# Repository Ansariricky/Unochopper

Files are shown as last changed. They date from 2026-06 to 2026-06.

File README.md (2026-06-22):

<<<<<<< HEAD
# Hardware

This repository contains hardware design files for various products and subsystems, including but not limited to:

- Flight Controllers (FC)
- Electronic Speed Controllers (ESC)
- Radio Control Systems (RC)
- Video Transmitters (VTX)
- Power Distribution Units (PDU)
- Sensor Boards
- Companion Computers
- Other supporting avionics and embedded hardware

## Naming Convention

Project directories shall follow the format:

    <MCU_OR_CPU>_<HARDWARE>_RevX

Examples:

    STM32F405_FlightController_Rev1
    STM32F405_ESC_Rev1
    ESP32S3_RC_Rev1
    ESP32S3_VTX_Rev1
    RPiCM4_CompanionComputer_Rev1

### Rules

- Use underscores (_) as separators.
- Do not use spaces in directory names.
- MCU/CPU name must appear first.
- Hardware name must appear second.
- Revision number must appear last.

## Repository Contents

Each project directory may contain:

- Schematics
- PCB Layouts
- Manufacturing Files
- Bill of Materials (BOM)
- Assembly Documentation
- Design Notes

## Revision Policy

New hardware revisions shall be created as separate directories following the established naming convention. Previous revisions should be retained for traceability and historical reference.

=======
# Hardware

This repository contains hardware design files for various products and subsystems, including but not limited to:

- Flight Controllers (FC)
- Electronic Speed Controllers (ESC)
- Radio Control Systems (RC)
- Video Transmitters (VTX)
- Power Distribution Units (PDU)
- Sensor Boards
- Companion Computers
- Other supporting avionics and embedded hardware

## Naming Convention

Project directories shall follow the format:

    <MCU_OR_CPU>_<HARDWARE>_RevX

Examples:

    STM32F405_FlightController_Rev1
    STM32F405_ESC_Rev1
    ESP32S3_RC_Rev1
    ESP32S3_VTX_Rev1
    RPiCM4_CompanionComputer_Rev1

### Rules

- Use underscores (_) as separators.
- Do not use spaces in directory names.
- MCU/CPU name must appear first.
- Hardware name must appear second.
- Revision number must appear last.

## Repository Contents

Each project directory may contain:

- Schematics
- PCB Layouts
- Manufacturing Files
- Bill of Materials (BOM)
- Assembly Documentation
- Design Notes

## Revision Policy

New hardware revisions shall be created as separate directories following the established naming convention. Previous revisions should be retained for traceability and historical reference.

>>>>>>> 076c8ab1df7aa20a5a2c2d71f1c9e05963331e4d

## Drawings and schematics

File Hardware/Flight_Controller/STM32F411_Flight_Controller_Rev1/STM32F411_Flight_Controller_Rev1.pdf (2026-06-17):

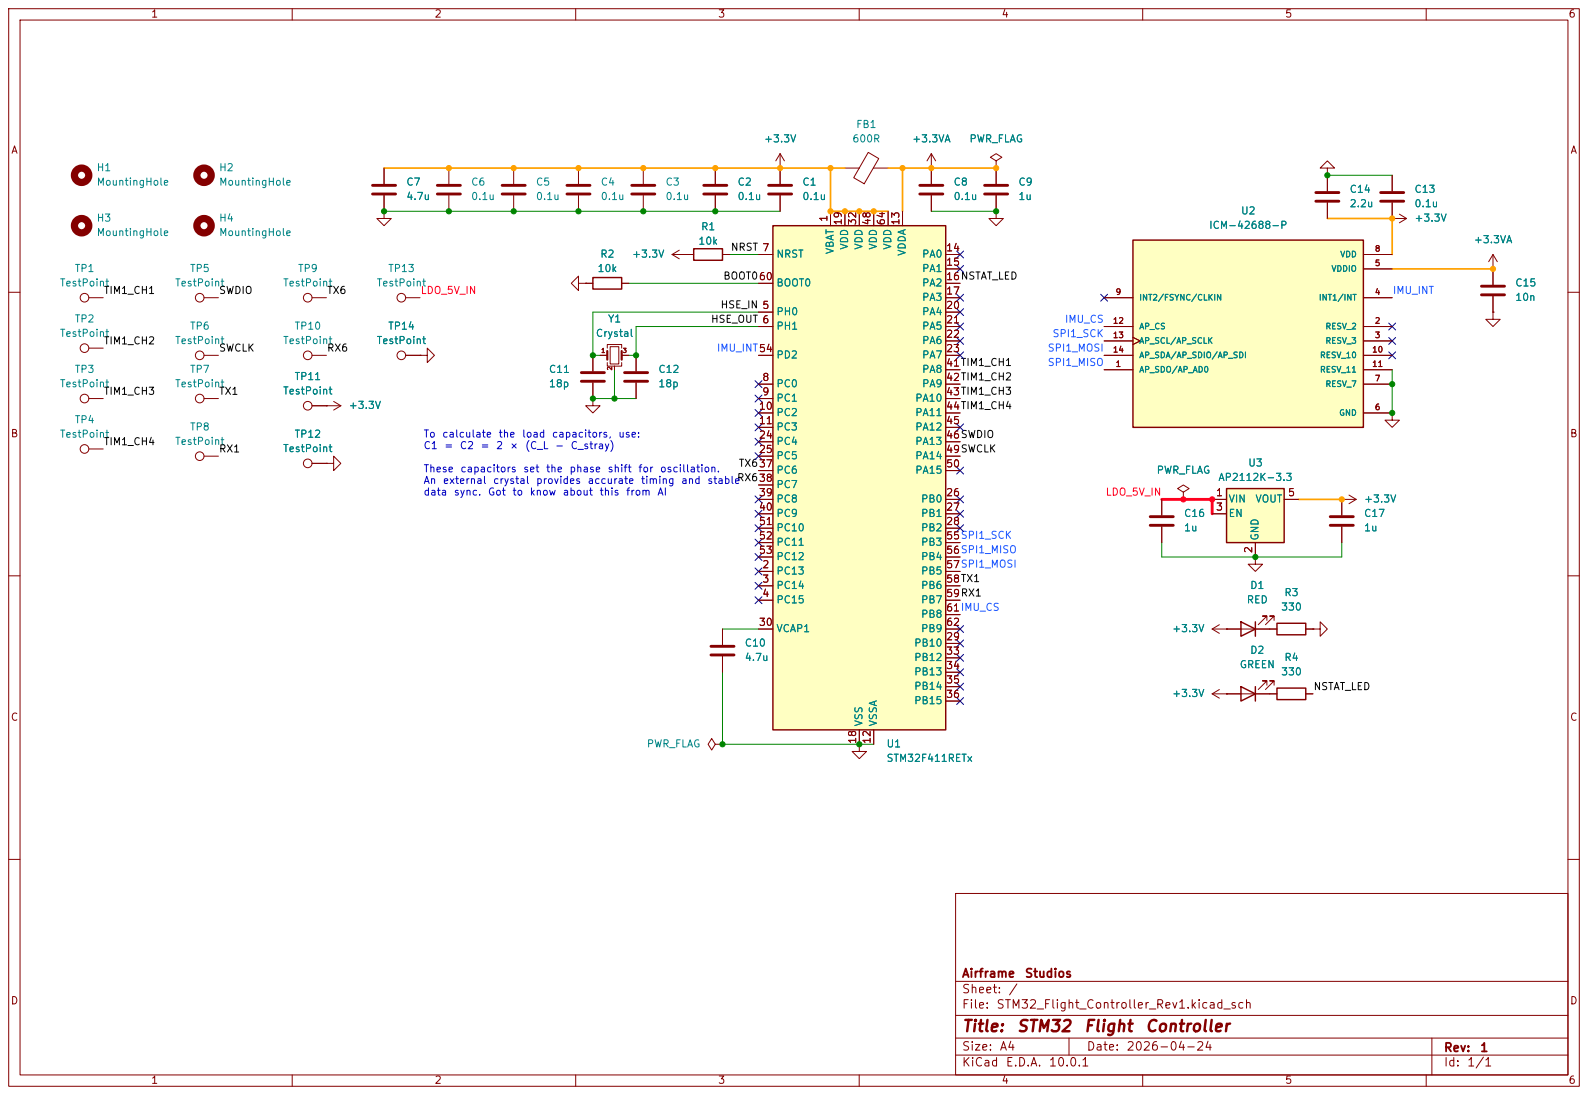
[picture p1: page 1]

Size: A4 | Rev: 1
KiCad E.D.A. 10.0.1 | Id: 1/1

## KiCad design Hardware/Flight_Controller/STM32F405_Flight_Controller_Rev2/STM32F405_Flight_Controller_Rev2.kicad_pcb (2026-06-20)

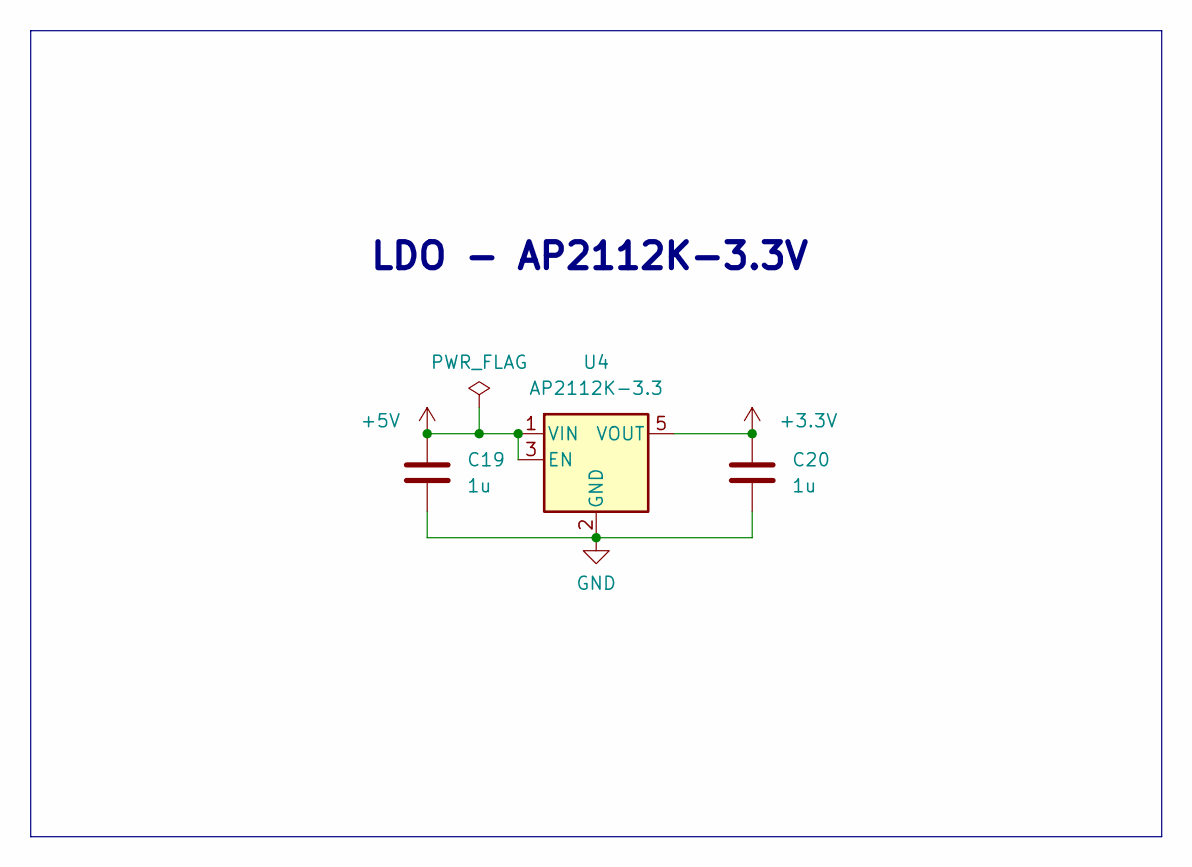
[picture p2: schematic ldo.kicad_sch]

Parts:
C19, C20: 1u; C_0603_1608Metric_Pad1.08x0.95mm_HandSolder
U4: AP2112K-3.3; SOT-23-5

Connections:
+3.3V: C20.1, U4.5 (VOUT); also elsewhere on the board
+5V: C19.1, U4.1 (VIN), U4.3 (EN); also elsewhere on the board
GND: C19.2, C20.2, U4.2 (GND); also elsewhere on the board

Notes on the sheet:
LDO - AP2112K-3.3V

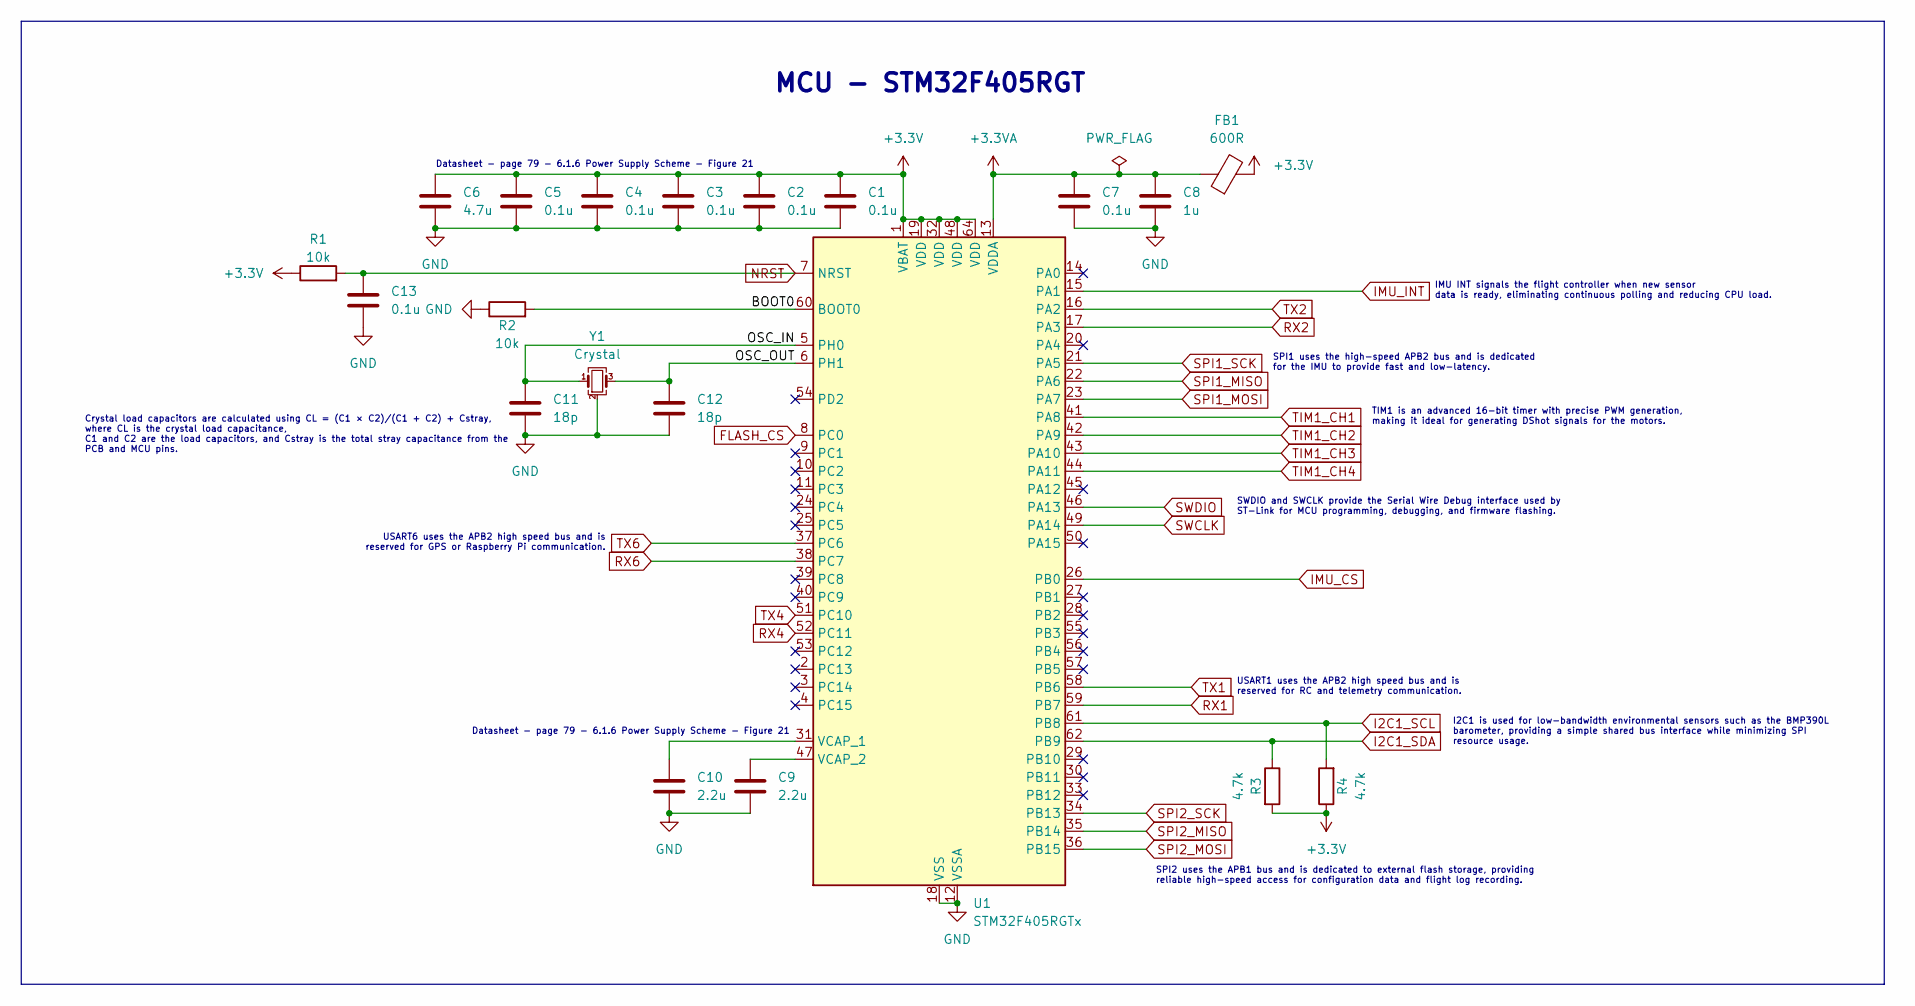
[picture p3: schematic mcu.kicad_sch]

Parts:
C1, C2, C3, C4, C5, C7, C13: 0.1u; C_0603_1608Metric_Pad1.08x0.95mm_HandSolder
C6: 4.7u; C_0603_1608Metric_Pad1.08x0.95mm_HandSolder
C8: 1u; C_0603_1608Metric_Pad1.08x0.95mm_HandSolder
C9, C10: 2.2u; C_0603_1608Metric_Pad1.08x0.95mm_HandSolder
C11, C12: 18p; C_0603_1608Metric_Pad1.08x0.95mm_HandSolder
FB1: 600R; L_0603_1608Metric_Pad1.05x0.95mm_HandSolder
R1, R2: 10k; R_0603_1608Metric_Pad0.98x0.95mm_HandSolder
R3, R4: 4.7k; R_0603_1608Metric_Pad0.98x0.95mm_HandSolder
U1: STM32F405RGTx; LQFP-64_10x10mm_P0.5mm
Y1: Crystal; Crystal_SMD_3225-4Pin_3.2x2.5mm_HandSoldering

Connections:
+3.3V: C1.1, C2.1, C3.1, C4.1, C5.1, C6.1, FB1.2, R1.1, R3.2, R4.1, U1.1 (VBAT), U1.19 (VDD), U1.32 (VDD), U1.48 (VDD), U1.64 (VDD); also elsewhere on the board
+3.3VA: C7.1, C8.1, FB1.1, U1.13 (VDDA)
/MCU/BOOT0: R2.2, U1.60 (BOOT0)
/MCU/OSC_IN: C11.1, U1.5 (PH0), Y1.1
/MCU/OSC_OUT: C12.1, U1.6 (PH1), Y1.3
FLASH_CS: U1.8 (PC0); also elsewhere on the board
GND: C1.2, C2.2, C3.2, C4.2, C5.2, C6.2, C7.2, C8.2, C9.2, C10.2, C11.2, C12.2, C13.2, R2.1, U1.12 (VSSA), U1.18 (VSS), U1.63 (VSS), Y1.2 (G), Y1.4 (G); also elsewhere on the board
I2C1_SCL: R4.2, U1.61 (PB8); also elsewhere on the board
I2C1_SDA: R3.1, U1.62 (PB9); also elsewhere on the board
IMU_CS: U1.26 (PB0); also elsewhere on the board
IMU_INT: U1.15 (PA1); also elsewhere on the board
NRST: C13.1, R1.2, U1.7 (NRST)
unnamed: C10.1, U1.31 (VCAP_1)
unnamed: C9.1, U1.47 (VCAP_2)
RX1: U1.59 (PB7); also elsewhere on the board
RX2: U1.17 (PA3); also elsewhere on the board
RX4: U1.52 (PC11); also elsewhere on the board
RX6: U1.38 (PC7); also elsewhere on the board
SPI1_MISO: U1.22 (PA6); also elsewhere on the board
SPI1_MOSI: U1.23 (PA7); also elsewhere on the board
SPI1_SCK: U1.21 (PA5); also elsewhere on the board
SPI2_MISO: U1.35 (PB14); also elsewhere on the board
SPI2_MOSI: U1.36 (PB15); also elsewhere on the board
SPI2_SCK: U1.34 (PB13); also elsewhere on the board
SWCLK: U1.49 (PA14); also elsewhere on the board
SWDIO: U1.46 (PA13); also elsewhere on the board
TIM1_CH1: U1.41 (PA8); also elsewhere on the board
TIM1_CH2: U1.42 (PA9); also elsewhere on the board
TIM1_CH3: U1.43 (PA10); also elsewhere on the board
TIM1_CH4: U1.44 (PA11); also elsewhere on the board
TX1: U1.58 (PB6); also elsewhere on the board
TX2: U1.16 (PA2); also elsewhere on the board
TX4: U1.51 (PC10); also elsewhere on the board
TX6: U1.37 (PC6); also elsewhere on the board

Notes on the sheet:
MCU - STM32F405RGT
IMU INT signals the flight controller when new sensor data is ready, eliminating continuous polling and reducing CPU load.
SPI2 uses the APB1 bus and is dedicated to external flash storage, providing reliable high-speed access for configuration data and flight log recording.
Crystal load capacitors are calculated using CL = (C1 × C2)/(C1 + C2) + Cstray, where CL is the crystal load capacitance, C1 and C2 are the load capacitors, and Cstray is the total stray capacitance from the PCB and MCU pins.
USART1 uses the APB2 high speed bus and is reserved for RC and telemetry communication.
SWDIO and SWCLK provide the Serial Wire Debug interface used by ST-Link for MCU programming, debugging, and firmware flashing.
I2C1 is used for low-bandwidth environmental sensors such as the BMP390L barometer, providing a simple shared bus interface while minimizing SPI resource usage.
TIM1 is an advanced 16-bit timer with precise PWM generation, making it ideal for generating DShot signals for the motors.
SPI1 uses the high-speed APB2 bus and is dedicated for the IMU to provide fast and low-latency.
USART6 uses the APB2 high speed bus and is reserved for GPS or Raspberry Pi communication.
Datasheet - page 79 - 6.1.6 Power Supply Scheme - Figure 21

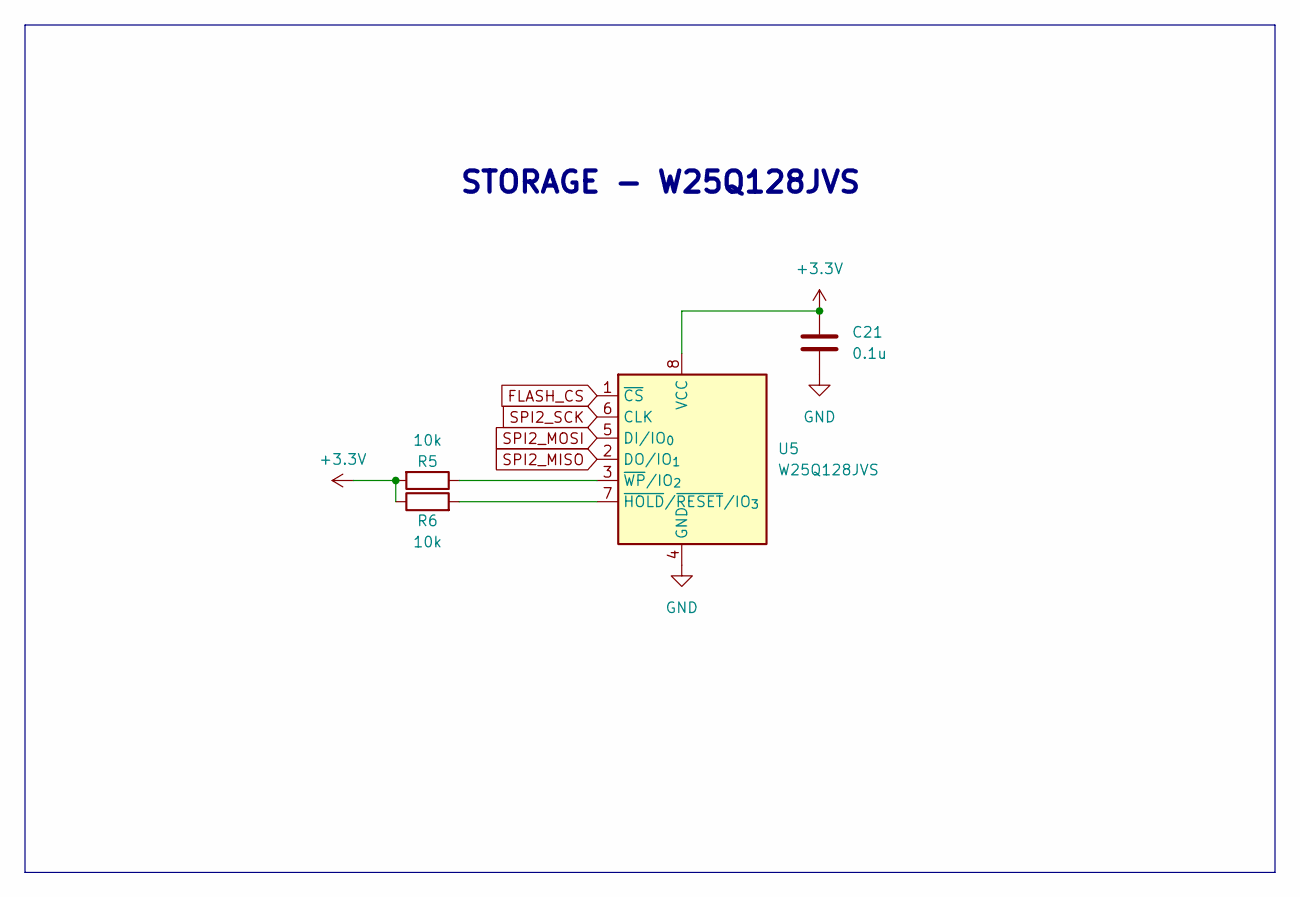
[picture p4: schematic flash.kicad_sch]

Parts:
C21: 0.1u; C_0603_1608Metric_Pad1.08x0.95mm_HandSolder
R5, R6: 10k; R_0603_1608Metric_Pad0.98x0.95mm_HandSolder
U5: W25Q128JVS; SOIC-8_5.3x5.3mm_P1.27mm

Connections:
+3.3V: C21.1, R5.2, R6.1, U5.8 (VCC); also elsewhere on the board
FLASH_CS: U5.1 (~CS); also elsewhere on the board
GND: C21.2, U5.4 (GND); also elsewhere on the board
unnamed: R6.2, U5.7 (~HOLD/~RESET/IO_{3})
unnamed: R5.1, U5.3 (~WP/IO_{2})
SPI2_MISO: U5.2 (DO/IO_{1}); also elsewhere on the board
SPI2_MOSI: U5.5 (DI/IO_{0}); also elsewhere on the board
SPI2_SCK: U5.6 (CLK); also elsewhere on the board

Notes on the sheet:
STORAGE - W25Q128JVS

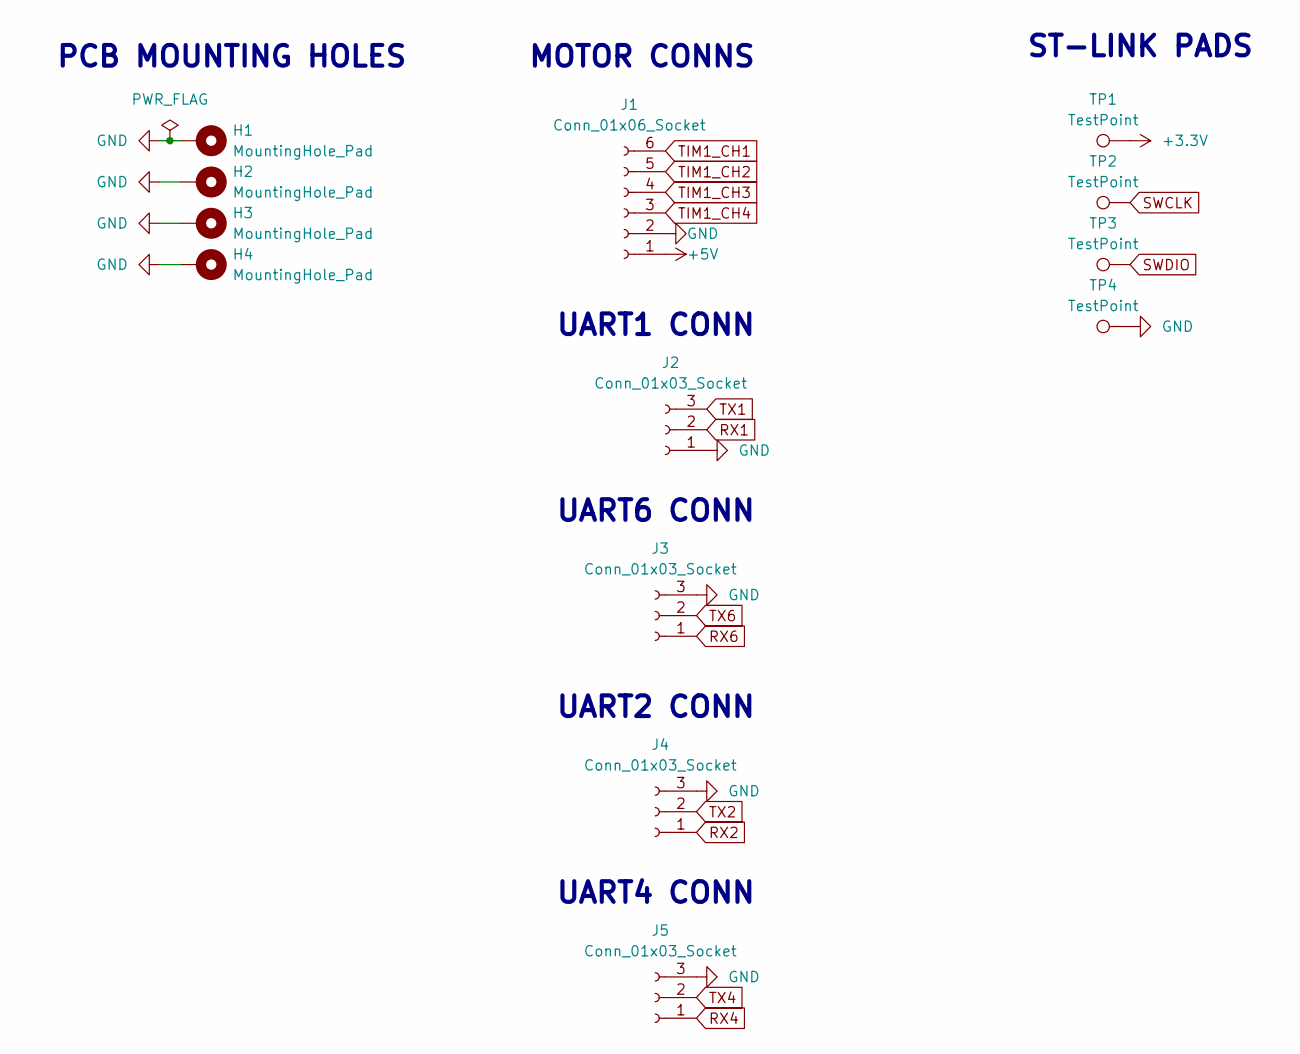
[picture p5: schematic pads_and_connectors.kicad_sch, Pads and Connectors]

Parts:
H1, H2, H3, H4: MountingHole_Pad; MountingHole_3.2mm_M3_Pad
J1: Conn_01x06_Socket; JST_SH_SM06B-SRSS-TB_1x06-1MP_P1.00mm_Horizontal
J2, J3, J4, J5: Conn_01x03_Socket; JST_SH_SM03B-SRSS-TB_1x03-1MP_P1.00mm_Horizontal
TP1, TP2, TP3, TP4: TestPoint; TestPoint_Pad_D1.5mm

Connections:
+3.3V: TP1.1 (1_1); also elsewhere on the board
+5V: J1.1; also elsewhere on the board
GND: H1.1 (1_1), H2.1 (1_1), H3.1 (1_1), H4.1 (1_1), J1.2, J2.1, J3.3, J4.3, J5.3, TP4.1 (1_1); also elsewhere on the board
RX1: J2.2; also elsewhere on the board
RX2: J4.1; also elsewhere on the board
RX4: J5.1; also elsewhere on the board
RX6: J3.1; also elsewhere on the board
SWCLK: TP2.1 (1_1); also elsewhere on the board
SWDIO: TP3.1 (1_1); also elsewhere on the board
TIM1_CH1: J1.6; also elsewhere on the board
TIM1_CH2: J1.5; also elsewhere on the board
TIM1_CH3: J1.4; also elsewhere on the board
TIM1_CH4: J1.3; also elsewhere on the board
TX1: J2.3; also elsewhere on the board
TX2: J4.2; also elsewhere on the board
TX4: J5.2; also elsewhere on the board
TX6: J3.2; also elsewhere on the board

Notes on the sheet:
UART2 CONN
UART4 CONN
UART1 CONN
MOTOR CONNS
UART6 CONN
PCB MOUNTING HOLES
ST-LINK PADS

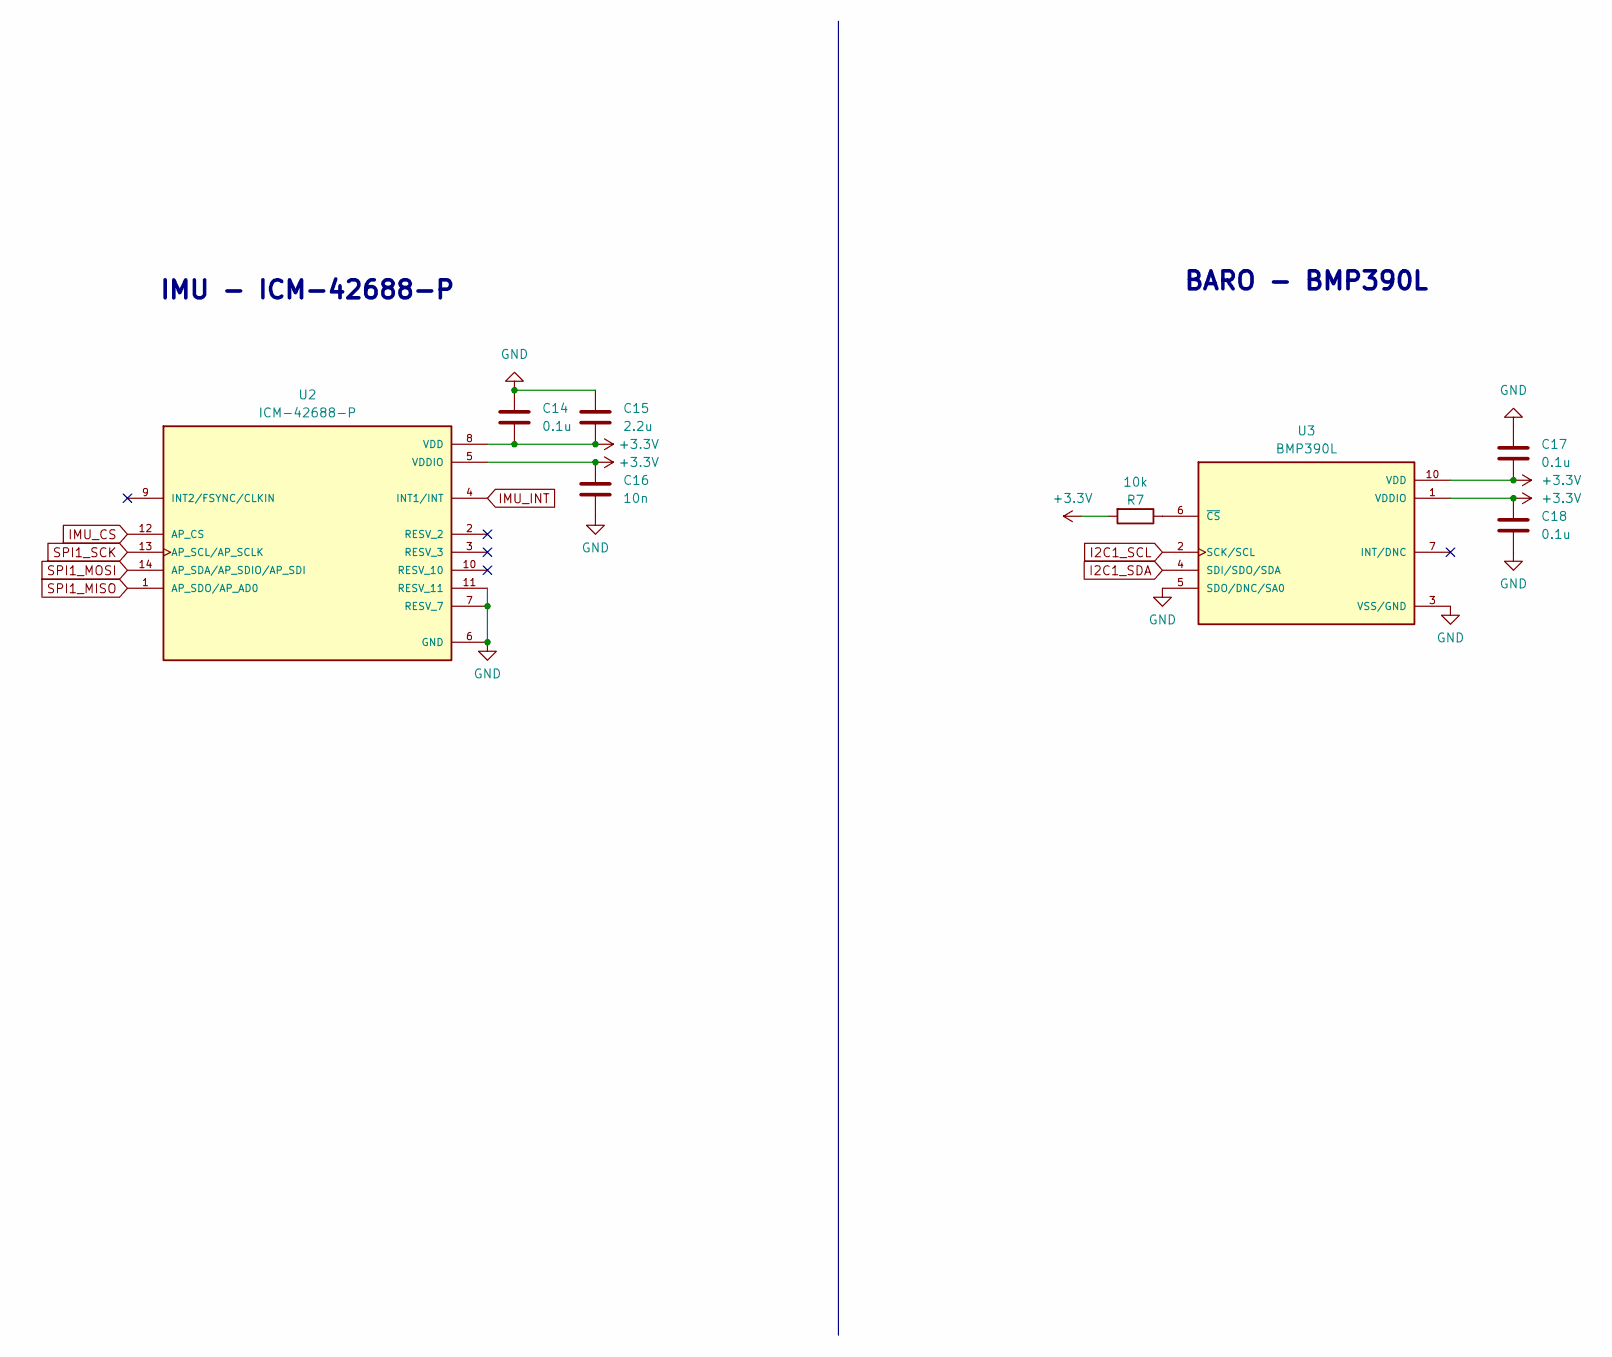
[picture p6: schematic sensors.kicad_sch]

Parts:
C14, C17, C18: 0.1u; C_0603_1608Metric_Pad1.08x0.95mm_HandSolder
C15: 2.2u; C_0603_1608Metric_Pad1.08x0.95mm_HandSolder
C16: 10n; C_0603_1608Metric_Pad1.08x0.95mm_HandSolder
R7: 10k; R_0603_1608Metric_Pad0.98x0.95mm_HandSolder
U2: ICM-42688-P; PARTREV 1.2
U3: BMP390L; PARTREV 1.7

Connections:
+3.3V: C14.2, C15.2, C16.1, C17.1, C18.1, R7.2, U2.5 (VDDIO), U2.8 (VDD), U3.1 (VDDIO), U3.10 (VDD); also elsewhere on the board
GND: C14.1, C15.1, C16.2, C17.2, C18.2, U2.6 (GND), U2.7 (RESV_7), U2.11 (RESV_11), U3.3 (VSS/GND), U3.5 (SDO/DNC/SA0), U3.8 (VSS/GND), U3.9 (VSS/GND); also elsewhere on the board
I2C1_SCL: U3.2 (SCK/SCL); also elsewhere on the board
I2C1_SDA: U3.4 (SDI/SDO/SDA); also elsewhere on the board
IMU_CS: U2.12 (AP_CS); also elsewhere on the board
IMU_INT: U2.4 (INT1/INT); also elsewhere on the board
unnamed: R7.1, U3.6 (~CS)
SPI1_MISO: U2.1 (AP_SDO/AP_AD0); also elsewhere on the board
SPI1_MOSI: U2.14 (AP_SDA/AP_SDIO/AP_SDI); also elsewhere on the board
SPI1_SCK: U2.13 (AP_SCL/AP_SCLK); also elsewhere on the board

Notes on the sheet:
IMU - ICM-42688-P
BARO - BMP390L

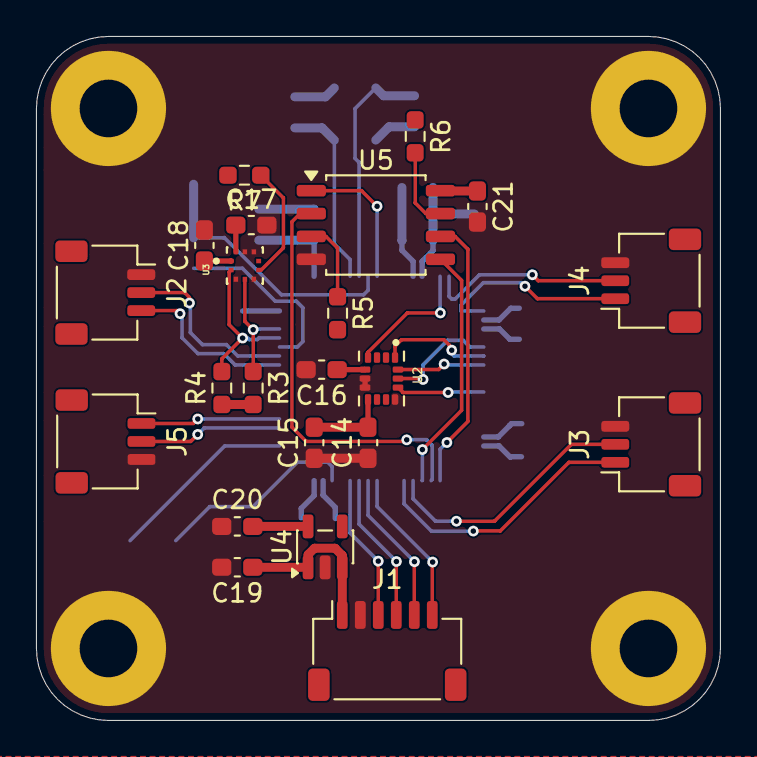
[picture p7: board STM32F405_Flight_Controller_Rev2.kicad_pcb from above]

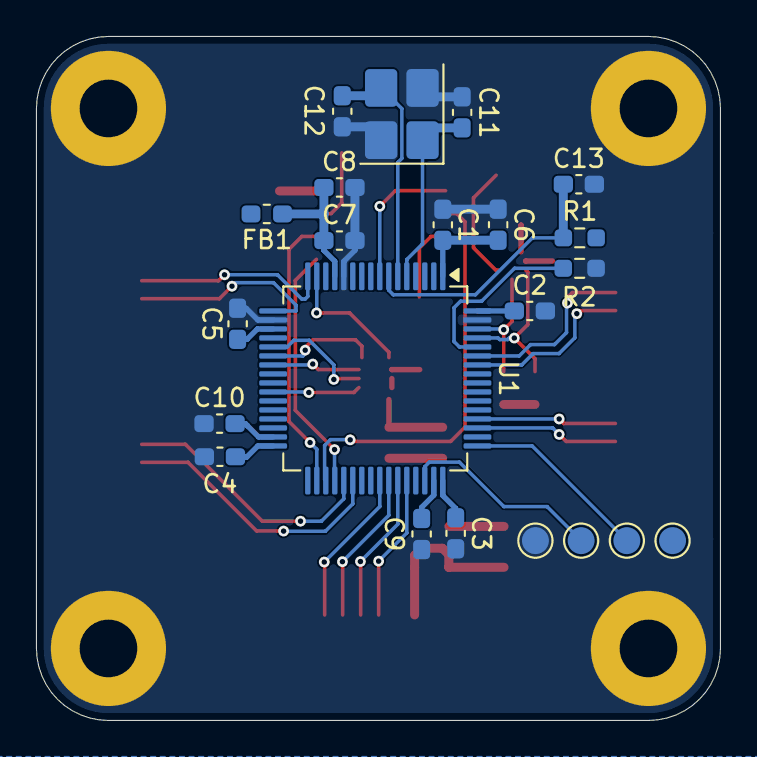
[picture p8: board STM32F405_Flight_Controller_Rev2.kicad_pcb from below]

Board: 4 copper layers, 38.0 x 38.0 mm, 48 parts (22 on the bottom side), 38 nets.

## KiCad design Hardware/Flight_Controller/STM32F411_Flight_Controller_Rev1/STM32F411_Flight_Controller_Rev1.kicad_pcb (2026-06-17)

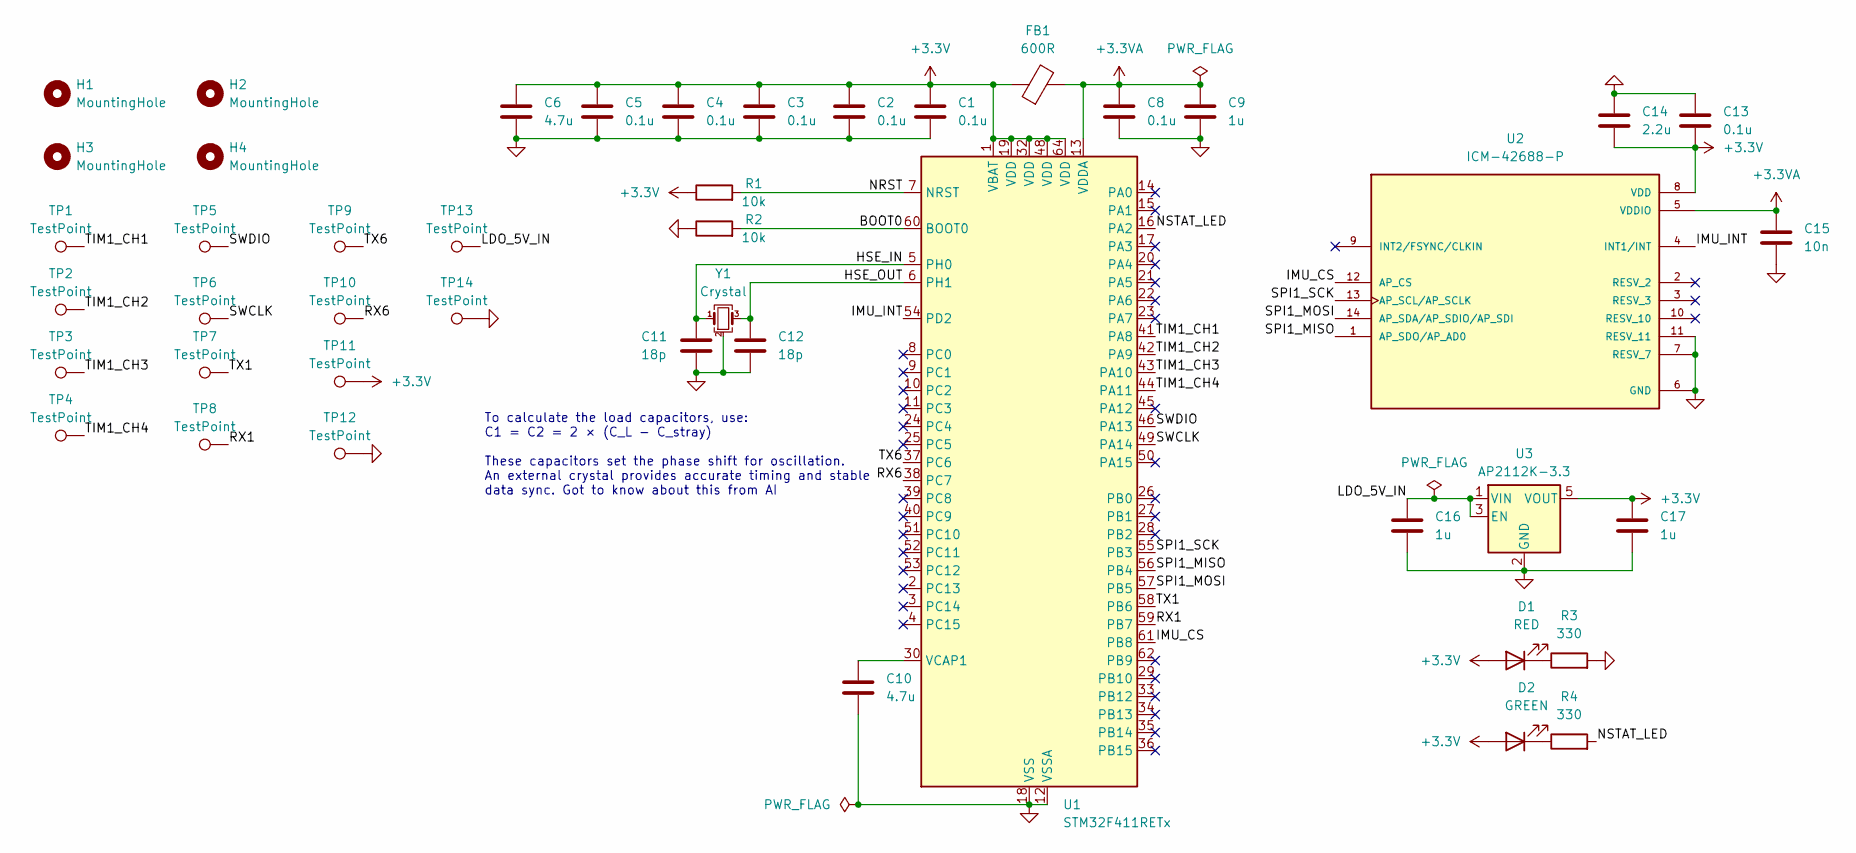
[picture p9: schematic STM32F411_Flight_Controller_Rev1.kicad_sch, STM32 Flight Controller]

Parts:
C1, C2, C3, C4, C5, C8, C13: 0.1u; C_0603_1608Metric_Pad1.08x0.95mm_HandSolder
C6, C10: 4.7u; C_0603_1608Metric_Pad1.08x0.95mm_HandSolder
C9, C16, C17: 1u; C_0603_1608Metric_Pad1.08x0.95mm_HandSolder
C11, C12: 18p; C_0603_1608Metric_Pad1.08x0.95mm_HandSolder
C14: 2.2u; C_0603_1608Metric_Pad1.08x0.95mm_HandSolder
C15: 10n; C_0603_1608Metric_Pad1.08x0.95mm_HandSolder
D1: RED; LED_0603_1608Metric_Pad1.05x0.95mm_HandSolder
D2: GREEN; LED_0603_1608Metric_Pad1.05x0.95mm_HandSolder
FB1: 600R; L_0603_1608Metric_Pad1.05x0.95mm_HandSolder
H1, H2, H3, H4: MountingHole; MountingHole_3.2mm_M3
R1, R2: 10k; R_0603_1608Metric_Pad0.98x0.95mm_HandSolder
R3, R4: 330; R_0603_1608Metric_Pad0.98x0.95mm_HandSolder
TP1, TP2, TP3, TP4, TP5, TP6, TP7, TP8, TP9, TP10, TP11, TP12, TP13, TP14: TestPoint; TestPoint_THTPad_1.0x1.0mm_Drill0.5mm
U1: STM32F411RETx; LQFP-64_10x10mm_P0.5mm
U2: ICM-42688-P; PARTREV 1.2
U3: AP2112K-3.3; SOT-23-5
Y1: Crystal; Crystal_SMD_3225-4Pin_3.2x2.5mm_HandSoldering

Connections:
+3.3V: C1.1, C2.1, C3.1, C4.1, C5.1, C6.1, C13.1, C14.1, C17.2, D1.2 (A), D2.2 (A), FB1.1, R1.1, TP11.1 (1_1), U1.1 (VBAT), U1.19 (VDD), U1.32 (VDD), U1.48 (VDD), U1.64 (VDD), U2.8 (VDD), U3.5 (VOUT); also elsewhere on the board
+3.3VA: C8.1, C9.1, C15.2, FB1.2, U1.13 (VDDA), U2.5 (VDDIO)
/BOOT0: R2.2, U1.60 (BOOT0)
/HSE_IN: C11.1, U1.5 (PH0), Y1.1
/HSE_OUT: C12.1, U1.6 (PH1), Y1.3
/IMU_CS: U1.61 (PB8), U2.12 (AP_CS)
/IMU_INT: U1.54 (PD2), U2.4 (INT1/INT)
/LDO_5V_IN: C16.2, TP13.1 (1_1), U3.1 (VIN), U3.3 (EN)
/NRST: R1.2, U1.7 (NRST)
/NSTAT_LED: R4.2, U1.16 (PA2)
/RX1: TP8.1 (1_1), U1.59 (PB7)
/RX6: TP10.1 (1_1), U1.38 (PC7)
/SPI1_MISO: U1.56 (PB4), U2.1 (AP_SDO/AP_AD0)
/SPI1_MOSI: U1.57 (PB5), U2.14 (AP_SDA/AP_SDIO/AP_SDI)
/SPI1_SCK: U1.55 (PB3), U2.13 (AP_SCL/AP_SCLK)
/SWCLK: TP6.1 (1_1), U1.49 (PA14)
/SWDIO: TP5.1 (1_1), U1.46 (PA13)
/TIM1_CH1: TP1.1 (1_1), U1.41 (PA8)
/TIM1_CH2: TP2.1 (1_1), U1.42 (PA9)
/TIM1_CH3: TP3.1 (1_1), U1.43 (PA10)
/TIM1_CH4: TP4.1 (1_1), U1.44 (PA11)
/TX1: TP7.1 (1_1), U1.58 (PB6)
/TX6: TP9.1 (1_1), U1.37 (PC6)
GND: C1.2, C2.2, C3.2, C4.2, C5.2, C6.2, C8.2, C9.2, C10.2, C11.2, C12.2, C13.2, C14.2, C15.1, C16.1, C17.1, R2.1, R3.2, TP12.1 (1_1), TP14.1 (1_1), U1.12 (VSSA), U1.18 (VSS), U1.31 (VSS), U1.47 (VSS), U1.63 (VSS), U2.6 (GND), U2.7 (RESV_7), U2.11 (RESV_11), U3.2 (GND), Y1.2 (G), Y1.4 (G); also elsewhere on the board
unnamed: D1.1 (K), R3.1
unnamed: D2.1 (K), R4.1
unnamed: C10.1, U1.30 (VCAP1)

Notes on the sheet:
To calculate the load capacitors, use: C1 = C2 = 2 × (C_L − C_stray) These capacitors set the phase shift for oscillation. An external crystal provides accurate timing and stable data sync. Got to know about this from AI

Board: 4 copper layers, 46 parts (0 on the bottom side), 27 nets, no tracks yet.

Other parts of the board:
C7: 4.7u; C_0603_1608Metric_Pad1.08x0.95mm_HandSolder

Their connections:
+3.3V: C7.1; also elsewhere on the board
GND: C7.2; also elsewhere on the board

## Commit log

2026-06-17 Separate hardware and firmware
    [STM32F405_Flight_Controller_Rev2.kicad_pcb, STM32F405_Flight_Controller_Rev2.kicad_sch, STM32F411_Flight_Controller_Rev1.kicad_pcb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]
2026-06-17 Add firmware
    [sensors.kicad_sch]
2026-06-20 Ready Rev2 PCB
    [STM32F405_Flight_Controller_Rev2.kicad_pcb, STM32F405_Flight_Controller_Rev2.kicad_sch, flash.kicad_sch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]
